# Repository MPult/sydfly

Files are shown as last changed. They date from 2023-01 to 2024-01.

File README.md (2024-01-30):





Licence
<!-- PROJECT LOGO -->
<br />
<div align="center">

  <h3 align="center">Sydfly</h3>
  <h4>This is still under Developent</h4> 
  <h4> /syːd/ /flyːr/ </h4>
  <p align="center">
     LEDs for your PAX wardrobe, without the propriatary controller
    <!--<br />
    <a href="https://github.com/mpult/sydfly">View Demo</a>
    ·
    <a href="https://github.com/mpult/sydfly/issues">Report Bug</a>
    ·
    <a href="https://github.com/mpult/sydfly/issues">Request Feature</a>
  </p> -->
</div>

<!-- ABOUT THE PROJECT -->
## About The Project

<!-- [![Product Name Screen Shot][product-screenshot]](https://example.com) -->

I wanted to buy some LEDs, that turn off once I close the door, for my PAX wardrobe. Yet, the price tag convinced me to spend thousands in learning PCB design and creating my own. (No I'm not OK) 

Here's why you should use this:
* You value open-source over time efficiency
* You're a cheapskate
* You hate spending money on a product that actually fully works, so instead you make it yourself.

<p align="right">(<a href="#readme-top">back to top</a>)</p>

<!-- GETTING STARTED -->
## Getting Started

Setting this up varies depending on how legit you want to make it: Own PCB? Or just on a breadboard?
### Parts list

Below is a list of parts required, each have their datasheet in the ``Datasheets`` folder. The links shown are for ``conrad.de``, I am not affiliated with them in any way.

| Count | Part No. | Part Name |
| ----- | --- | --- |
| 1 | A000005 | [Arduino Nano](https://www.conrad.de/de/p/arduino-board-nano-core-nano-atmega328-1172623.html) |
| 4 | DG350-3.5-03P-14-00AH-1 | [Degson Screw Terminal](https://www.conrad.de/de/p/degson-dg350-3-5-03p-14-00ah-1-schraubklemmblock-2-mm-polzahl-num-3-gruen-1-st-1327185.html) |
| 3 | IRLB8721PBF | [N-Channel MOSFET](https://www.conrad.de/de/p/infineon-technologies-irlb8721pbf-mosfet-1-n-kanal-65-w-to-220ab-161166.html) |
### Breadboard

1. Flash the code from ``Arduino-Code`` on to the Arduino [Instructions](https://support.arduino.cc/hc/en-us/articles/4733418441116-Upload-a-sketch-in-Arduino-IDE)
2. Build the breadboard following the [schematics](./Own-Schematics/Schematics.pdf), proper breadboard diagrams will follow soon (feel free to contribute!)
3. Enjoy the project!

**Optional Steps:**
1. 3D-Print the case from the ``CAD`` folder
2. Add a 45° diffuser for the stylish look

<p align="right">(<a href="#readme-top">back to top</a>)</p>

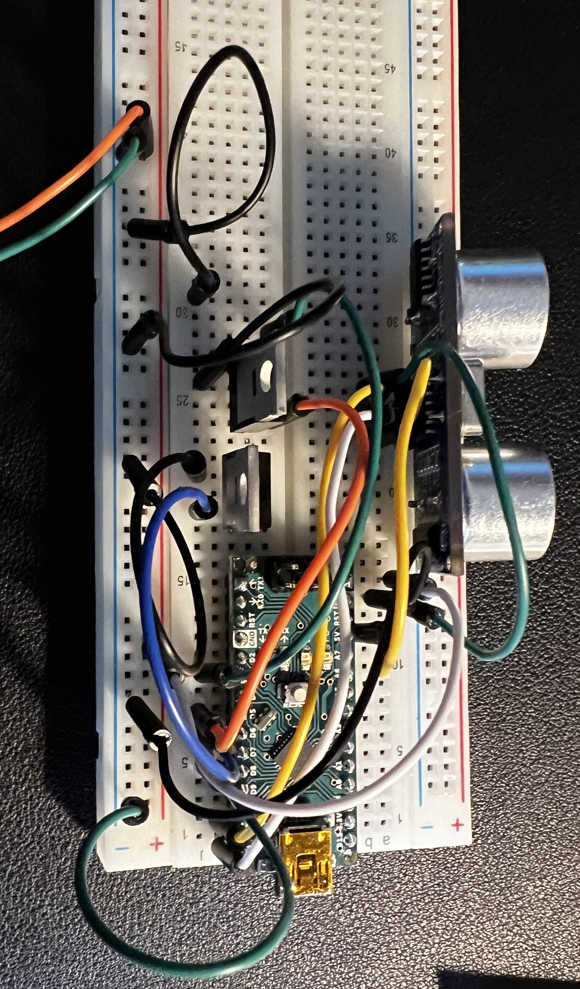
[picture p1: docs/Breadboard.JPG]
Breadboard Image


### PCB Route

Okay so you're hardcore and want to make your own PCB.

You can either use the Gerber files from the release, or make your own. Instructions to make the gerber files will follow soon™

1. Upload the **zipped** Gerber files from the release.
2. Select the options you want, only really important is 2 layered PCB. Rest is all preference
3. Order and wait.
4. Solder the components to the board following the [board Diagram](./Own-Schematics/Board.pdf)
5. Flash the code from ``Arduino-Code`` on to the Arduino [Instructions](https://support.arduino.cc/hc/en-us/articles/4733418441116-Upload-a-sketch-in-Arduino-IDE)
6. Done!

**Optional Steps:**
1. 3D-Print the case from the ``CAD`` folder
2. Add a 45° diffuser for the stylish look

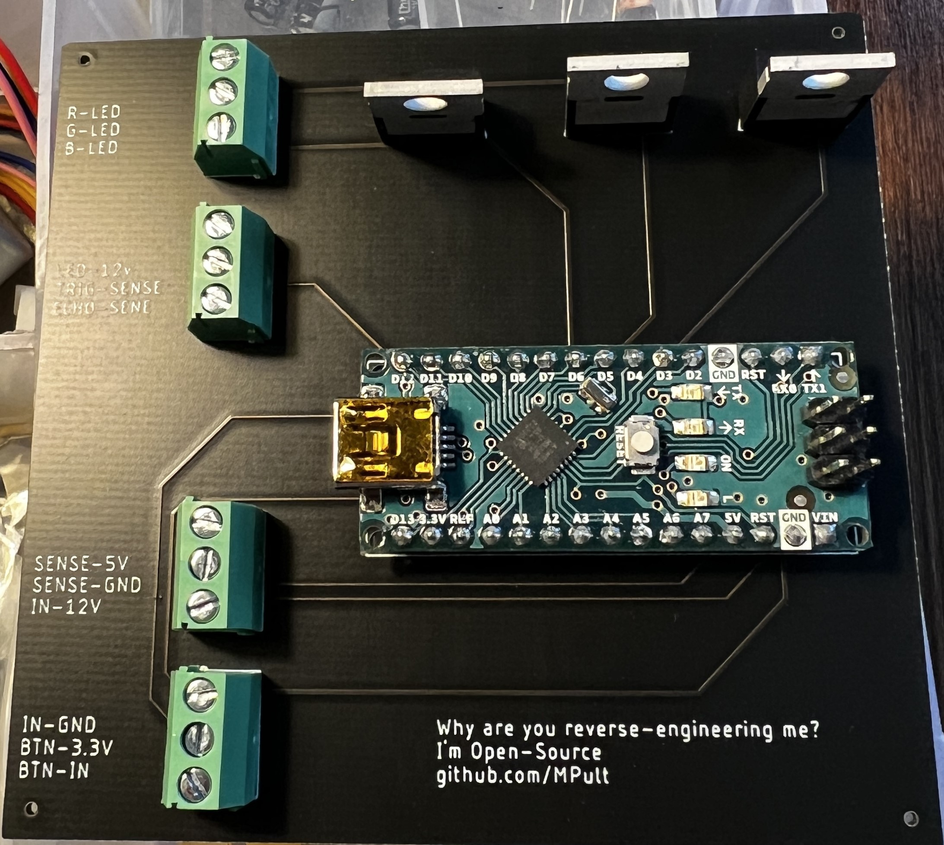
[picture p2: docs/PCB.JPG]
PC IMAGE


<p align="right">(<a href="#readme-top">back to top</a>)</p>

<!-- ROADMAP -->
## Roadmap

- [x] New README
- [x] Create Release
- [ ] Add multithreading
- [x] Add images to docs.

See the [open issues](https://github.com/mpult/sydfly/issues) for a full list of proposed features (and known issues).

<p align="right">(<a href="#readme-top">back to top</a>)</p>

<!-- CONTRIBUTING -->
## Contributing

Contributions are what make the open source community such an amazing place to learn, inspire, and create. Any contributions you make are **greatly appreciated**.

If you have a suggestion that would make this better, please fork the repo and create a pull request. You can also simply open an issue with the tag "enhancement".
Don't forget to give the project a star! Thanks again!

1. Fork the Project
2. Create your Feature Branch (`git checkout -b feature/AmazingFeature`)
3. Commit your Changes (`git commit -m 'Add some AmazingFeature'`)
4. Push to the Branch (`git push origin feature/AmazingFeature`)
5. Open a Pull Request

<p align="right">(<a href="#readme-top">back to top</a>)</p>

<!-- LICENSE -->
## License

Distributed under the MIT License. See `LICENSE` for more information.

<p align="right">(<a href="#readme-top">back to top</a>)</p>

<!-- ACKNOWLEDGMENTS -->
## Acknowledgments

* [Choose an Open Source License](https://choosealicense.com)
* [Img Shields](https://shields.io)
* [Markdown Template](https://github.com/othneildrew/Best-README-Template)
* [PCBway](https://pcbway.com)

# PCBway Review.

PCBway is the sponsor for this project!

**Disclaimer: I received the SYDFLY PCB prototype from PCBWay for free in exchange for writing this review.**

When it comes to open-source PCB projects, the quality of the prototypes can make a significant difference in the overall success of your project. I recently had the opportunity to try out PCBWay's services for the SYDFLY project, and I must say I'm quite impressed with the experience.

The continued collaboration with PCBWay has made the delevopment of this project possible. The service is honestly incredible, over multiple orders with them the quality has remained excelent. A coupple weeks after a order arrives a representative will reach out and ensure that everything is perfect.

Packaging:
First impressions matter, and PCBWay started off on the right foot with their packaging. The PCBs were carefully wrapped in bubble wrap and vacuum-sealed, ensuring that they arrived in pristine condition. This level of care in packaging demonstrates a commitment to quality and customer satisfaction.

Quality Assurance:
Upon opening the package, I examined the PCBs closely for defects. I'm pleased to report that there were none to be found. The boards looked immaculate, and the solder mask and silkscreen printing were sharp and well-executed. I also conducted a thorough conductivity and shorts check, and everything passed with flying colors. This attention to detail and quality control is crucial.

Finish Selection:
One important piece of advice I'd like to share is the importance of choosing the right finish for your PCBs. PCBWay offers a variety of finish options, and it's essential to select the one that suits your project. In my experience, the lead-free finish worked perfectly. However, it's worth noting that if you're not familiar with different finishes, seeking guidance is advisable to ensure compatibility with your components.

Shipping Speed and Cost:
I was pleasantly surprised by the efficiency of PCBWay's shipping service. Not only was it faster, but it was also more cost-effective compared to my previous experience with another PCB manufacturer. This is a significant advantage for anyone looking to get their prototypes quickly without breaking the bank.

Overall Impressions:
In conclusion, my experience with PCBWay for the SYDFLY project has been overwhelmingly positive. The quality of the PCBs, the attention to detail, and the reliable shipping service all contribute to an excellent overall experience. It's worth noting that the quality is on par with some of other well-known PCB manufacturers, which speaks volumes about PCBWay's capabilities.

In the interest of full transparency, I did receive these SYDFLY PCB prototypes from PCBWay at no cost in exchange for this review. However, I want to emphasize that my assessment is based solely on the quality of the product and the overall experience.

If you're working on an open-source PCB project like SYDFLY, I highly recommend giving PCBWay a try. Their commitment to quality, fast and affordable shipping, and range of finish options make them a strong contender in the PCB manufacturing space.

<!-- MARKDOWN LINKS & IMAGES -->
<!-- https://www.markdownguide.org/basic-syntax/#reference-style-links -->

[product-screenshot]: images/screenshot.png

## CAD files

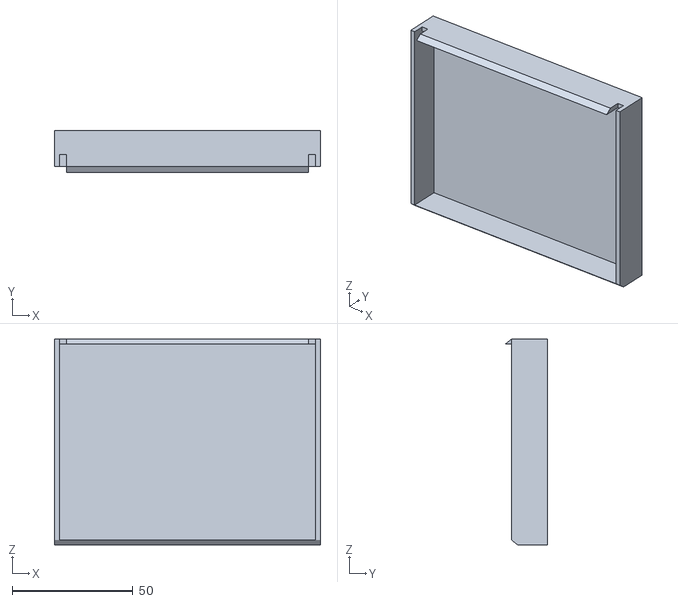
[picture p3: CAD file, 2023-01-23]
CAD/Case-Female.stl
110.0 x 17.5 x 85.0

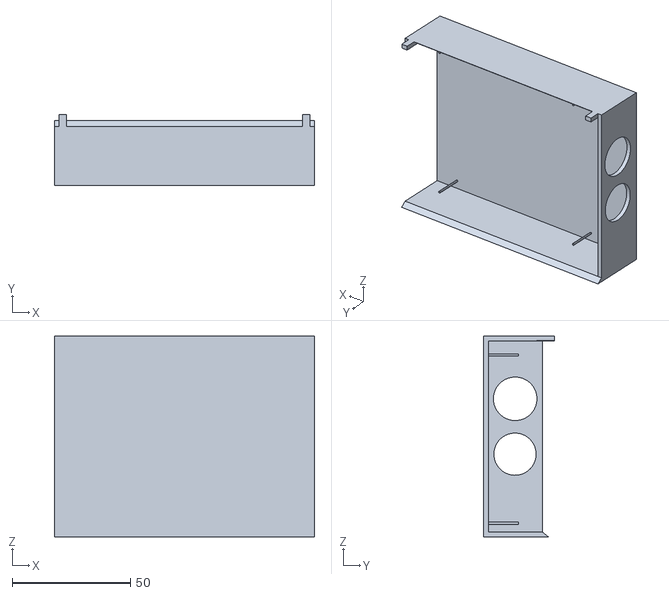
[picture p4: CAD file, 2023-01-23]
CAD/Case-Male.stl
110.0 x 30.0 x 85.0

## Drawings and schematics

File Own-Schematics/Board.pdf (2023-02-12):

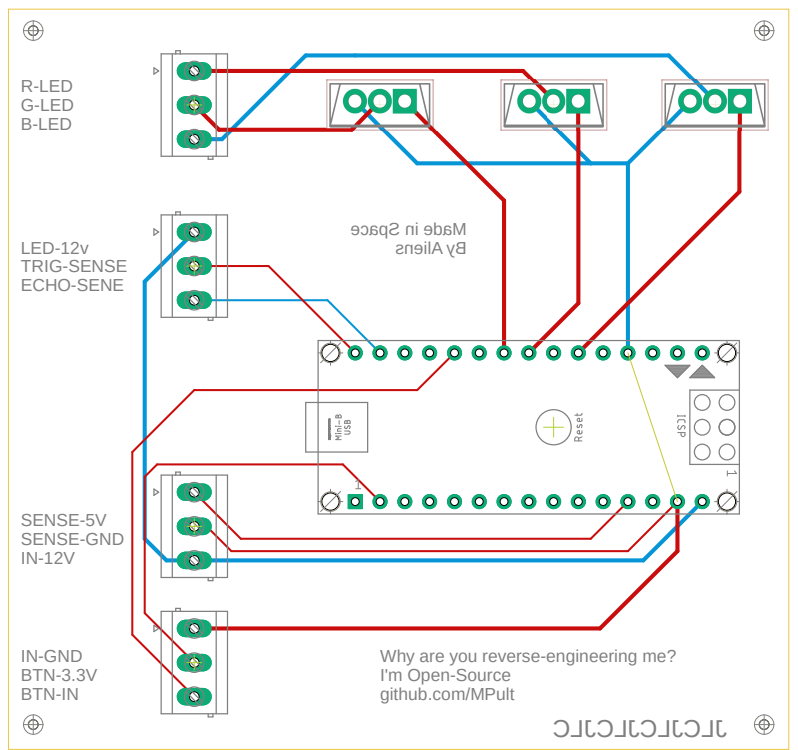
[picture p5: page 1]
R-LED G-LED B-LED; LED-12v TRIG-SENSE ECHO-SENE; SENSE-5V SENSE-GND IN-12V; IN-GND BTN-3.3V BTN-IN

Why are you reverse-engineering me?
I'm Open-Source
github.com/MPult

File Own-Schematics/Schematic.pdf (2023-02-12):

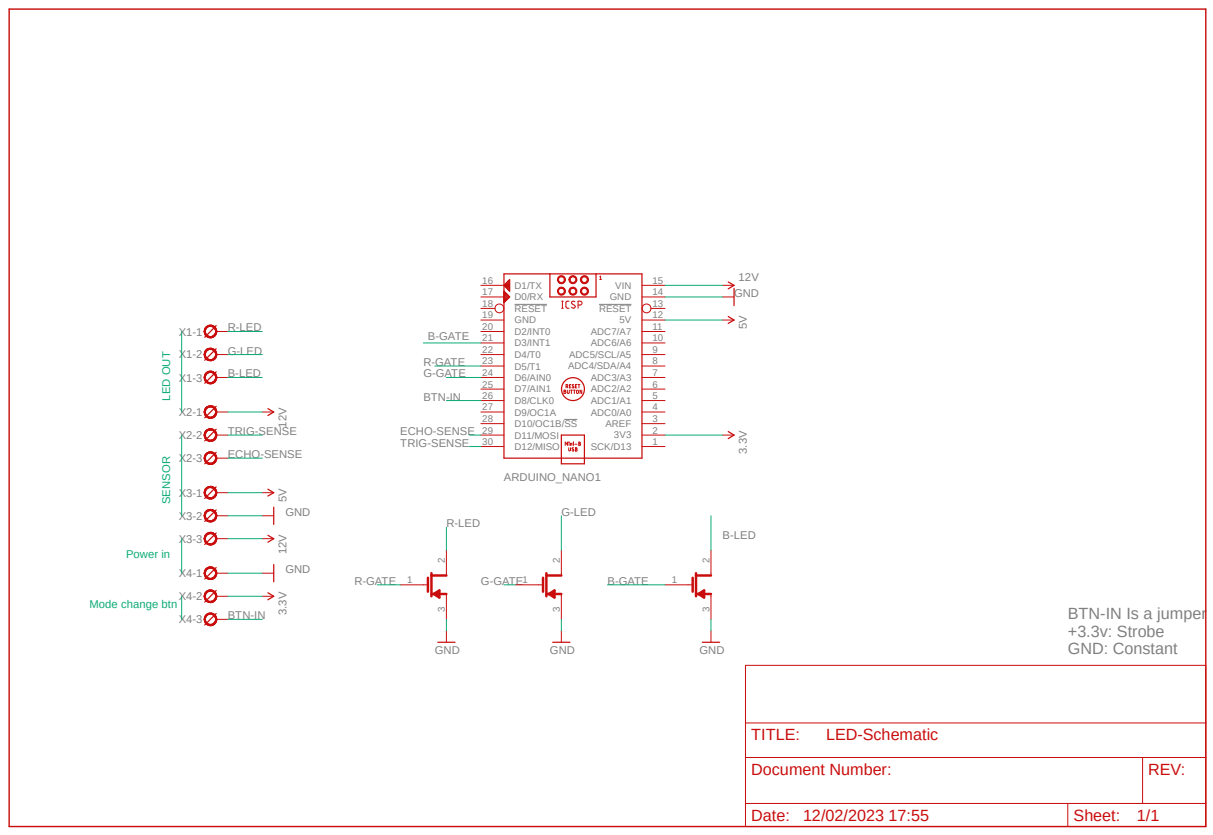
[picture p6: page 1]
GND; GND 5V; 12V 12V ¹²V; D1/TX 16 D0/RX 17 RESET 18 GND 19 D2/INT0 20 D3/INT1 21 D4/T0 22 D5/T1 23 D6/AIN0 24 D7/AIN1 25 D8/CLK0 26 D9/OC1A 27 D10/OC1B/SS 28 D11/MOSI 29; D12/MISO 30; SCK/D13; 2 AREF; 3 ADC0/A0; 4 ADC1/A1; 5 ADC2/A2; 6 ADC3/A3; 7 ADC4/SDA/A4; 8 ADC5/SCL/A5; 9 ADC6/A6; 10 ADC7/A7; 12 RESET; 13 GND; 14 VIN; ARDUINO_NANO1; R-LED; R-GATE; R-GATE G-GATE; G-GATE; B-GATE; G-LED; B-LED; TRIG-SENSE; ECHO-SENSE; BTN-IN; TITLE:; LED-Schematic; Power in

Mode change btnSENSOR LED OUT

BTN-IN Is a jumper
+3.3v: Strobe
GND: Constant

Document Number: | REV:

Date: 12/02/2023 17:55 | Sheet: 1/1

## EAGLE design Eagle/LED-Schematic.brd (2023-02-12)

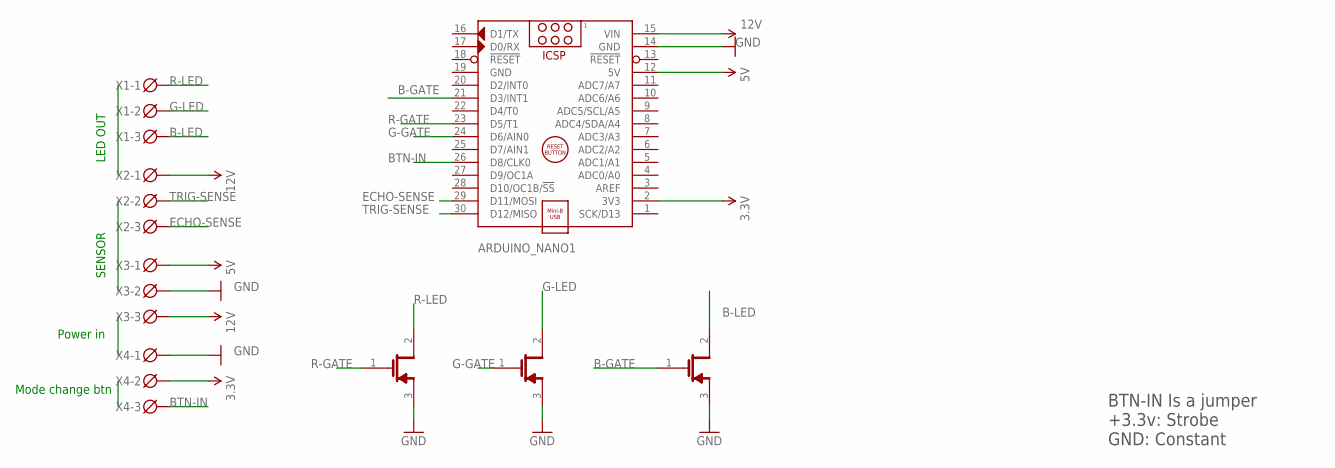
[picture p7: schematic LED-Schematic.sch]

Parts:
ARDUINO_NANO1: ARDUINO_NANO
Q1, Q2, Q3: INFINEON_IRLB8721PBFINFINEON_IRLB8721PBF_0_0; INFINEON_IRLB8721PBF_0
X1, X2, X3, X4: DG3XX-03-3.5; DG350-3.5-03P

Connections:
3.3V: ARDUINO_NANO1.2 (3V3), X4.2
5V: ARDUINO_NANO1.12 (5V), X3.1
12V: ARDUINO_NANO1.15 (VIN), X2.1, X3.3
B-GATE: ARDUINO_NANO1.21 (D3/INT1), Q3.1 (G)
B-LED: Q3.2 (D), X1.3
BTN-IN: ARDUINO_NANO1.26 (D8/CLK0), X4.3
ECHO-SENSE: ARDUINO_NANO1.29 (D11/MOSI), X2.3
G-GATE: ARDUINO_NANO1.24 (D6/AIN0), Q2.1 (G)
G-LED: Q2.2 (D), X1.2
GND: ARDUINO_NANO1.14 (GND), ARDUINO_NANO1.19 (GND), Q1.3 (S), Q2.3 (S), Q3.3 (S), X3.2, X4.1
R-GATE: ARDUINO_NANO1.23 (D5/T1), Q1.1 (G)
R-LED: Q1.2 (D), X1.1
TRIG-SENSE: ARDUINO_NANO1.30 (D12/MISO), X2.2

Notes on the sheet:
Power in
Mode change btn
SENSOR
LED OUT
BTN-IN Is a jumper +3.3v: Strobe GND: Constant

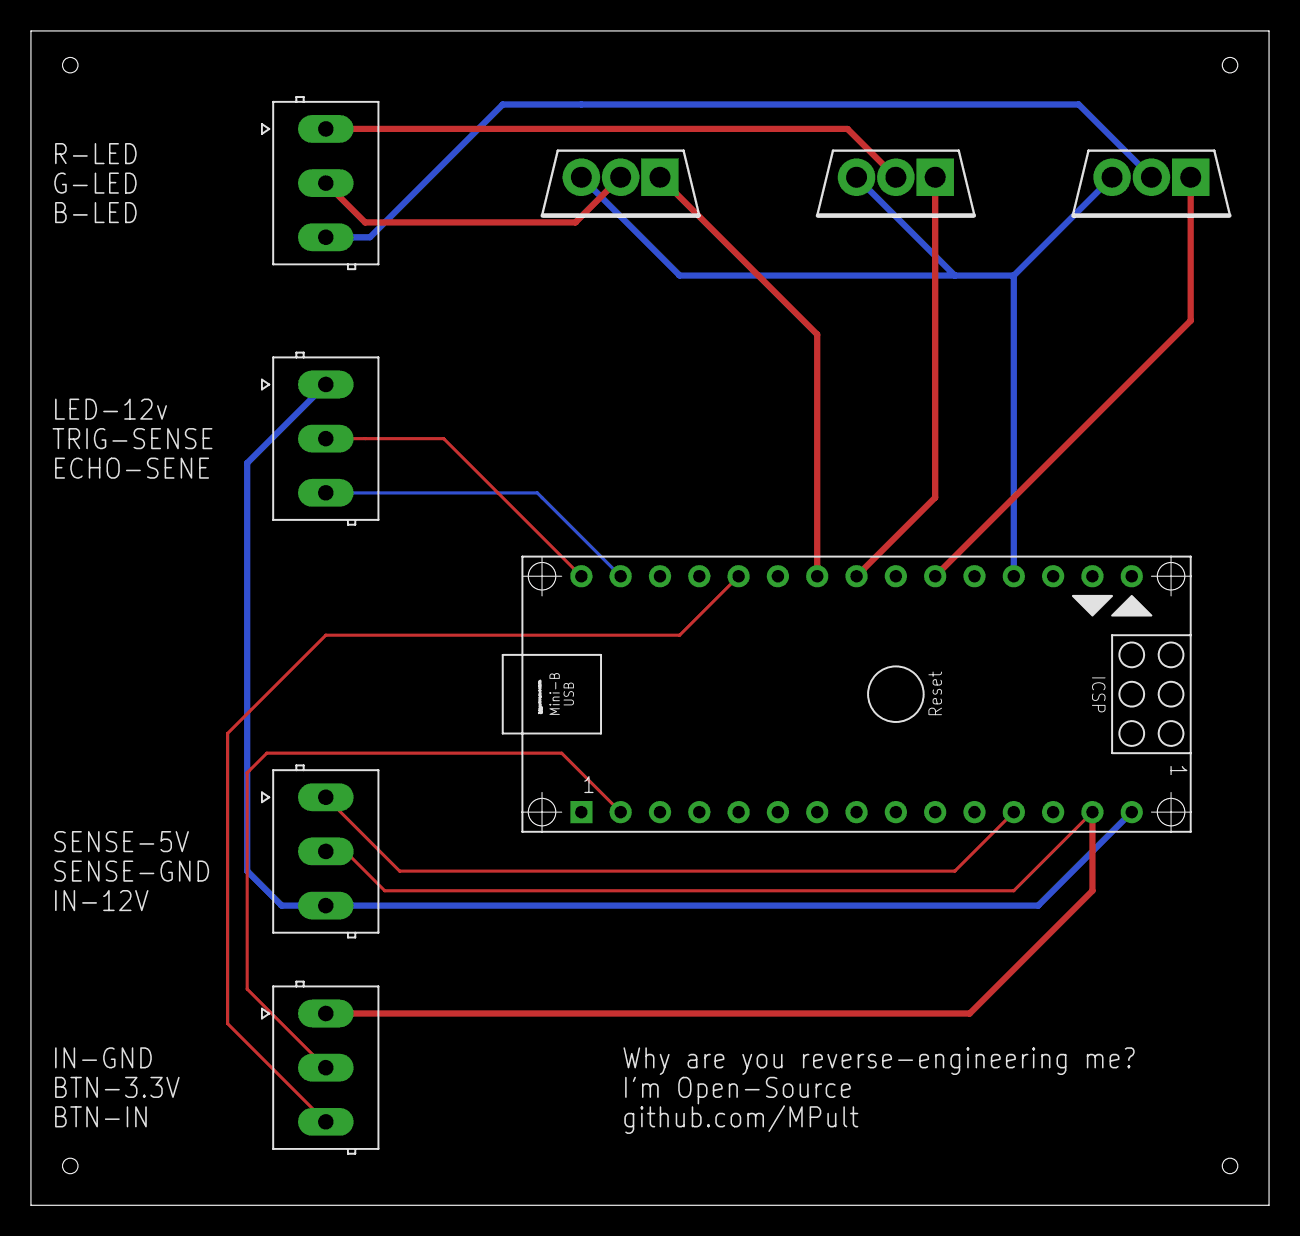
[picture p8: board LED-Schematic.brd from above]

Board: 2 copper layers, 80.0 x 75.9 mm, 8 parts (0 on the bottom side), 13 nets.

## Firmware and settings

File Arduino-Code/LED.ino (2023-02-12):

// color swirl! connect an RGB LED to the PWM pins as indicated
// in the #defines
// public domain, enjoy!

#define BLUEPIN 3//MEGA 3
#define REDPIN 5//MEGA 5
#define GREENPIN 6//MEGA 6

#define trigPin 12//MEGA 13
#define echoPin 11//MEGA 12

#define FADESPEED 4     // make this higher to slow down
#define distThreshold 20  // How high distance needs to be before starting LED
//#define mode 1 // 1: rgb fade, 2: const yellow

void setup() {
  Serial.begin(9600);
  pinMode(REDPIN, OUTPUT);
  pinMode(GREENPIN, OUTPUT);
  pinMode(BLUEPIN, OUTPUT);

  pinMode(trigPin, OUTPUT);
  pinMode(echoPin, INPUT);
  pinMode(8, INPUT);
}

void loop() {
  long duration, distance;
  digitalWrite(trigPin, LOW);  // Added this line
  delayMicroseconds(2);        // Added this line
  digitalWrite(trigPin, HIGH);
  //  delayMicroseconds(1000); - Removed this line
  delayMicroseconds(10);  // Added this line
  digitalWrite(trigPin, LOW);
  duration = pulseIn(echoPin, HIGH);
  distance = (duration / 2) / 29.1;

  Serial.print(distance);
  Serial.println(" cm");
  if (distance > distThreshold) {
    // LEDS need to be on, check what mode to be run
    bool strobe = digitalRead(8);
    Serial.println(strobe);
    if(strobe == true) {
    RGB(); 
    }
    if (strobe == false) {
      yellow();
    }
  } else {
    analogWrite(REDPIN, 0);
    analogWrite(BLUEPIN, 0);
    analogWrite(GREENPIN, 0);
  }
  delay(300);
}

void yellow() {
  analogWrite(REDPIN, 255);
  analogWrite(GREENPIN, 69);
  analogWrite(BLUEPIN, 0);
}

void RGB() {
  int r, g, b;
  Serial.print(r);
  Serial.print(",");
  Serial.print(g);
  Serial.print(",");
  Serial.println(b);
  // fade from blue to violet
  for (r = 0; r < 256; r++) { 
    analogWrite(REDPIN, r);
    delay(FADESPEED);
  } 
  // fade from violet to red
  for (b = 255; b > 0; b--) { 
    analogWrite(BLUEPIN, b);
    delay(FADESPEED);
  } 
  // fade from red to yellow
  for (g = 0; g < 256; g++) { 
    analogWrite(GREENPIN, g);
    delay(FADESPEED);
  } 
  // fade from yellow to green
  for (r = 255; r > 0; r--) { 
    analogWrite(REDPIN, r);
    delay(FADESPEED);
  } 
  // fade from green to teal
  for (b = 0; b < 256; b++) { 
    analogWrite(BLUEPIN, b); 
    delay(FADESPEED);
  } 
  // fade from teal to blue
  for (g = 255; g > 0; g--) { 
    analogWrite(GREENPIN, g);
    delay(FADESPEED);
  } 
}

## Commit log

2023-01-15 PCB design
    [LED-Schematic.brd, LED-Schematic.sch]
2023-01-16 Added arduino to schematic, added PCB board, added gitignore
    [LED-Schematic.brd, LED-Schematic.sch]
2023-01-17 swapped mosfets to infineon IRLs
    [LED-Schematic.brd, LED-Schematic.sch]
2023-01-20 Adding Datasheets, replace screw terms
    [LED-Schematic.brd, LED-Schematic.sch]
2023-01-20 Before reroute
    [LED-Schematic.brd, LED-Schematic.sch]
2023-01-20 addign silk screen labels
    [LED-Schematic.brd]
2023-01-22 Last Revamp, i promise
    [DRILEGEND.CFG, LED-Schematic.brd, LED-Schematic.sch]
2023-01-23 Adding Case 3D Model
    [Case-Female.stl, Case-Male.stl]
2023-01-26 Adding PCB Design export
    [LED-Schematic.sch]
2023-02-12 Final Edits before production
    [LED-Schematic.brd, LED-Schematic.sch]
2023-02-13 Revamping DOcs
    [DRILEGEND.CFG, LED-Schematic.brd, LED-Schematic.sch]
2023-03-14 Generating new Gerber Files for Production

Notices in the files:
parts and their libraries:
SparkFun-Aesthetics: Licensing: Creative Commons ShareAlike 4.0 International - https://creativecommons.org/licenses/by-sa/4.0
